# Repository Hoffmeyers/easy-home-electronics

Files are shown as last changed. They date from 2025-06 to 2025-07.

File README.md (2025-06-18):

This KiCad project showcases the design of a smart switch system built around the ESP32 microcontroller, aimed at enhancing automation and energy monitoring in residential or commercial settings. The system integrates both 5V and 3.3V low-dropout (LDO) voltage regulators to ensure stable power delivery to the ESP32 and associated components. An AC-DC converter is used to step down and convert mains voltage into usable DC power, making the switch compatible with standard household wiring. Additionally, the circuit incorporates voltage and current sensors to enable real-time power consumption monitoring, allowing users to track energy usage and implement protective features. The layout is optimized for compactness and reliability, with clear signal routing and robust power distribution.

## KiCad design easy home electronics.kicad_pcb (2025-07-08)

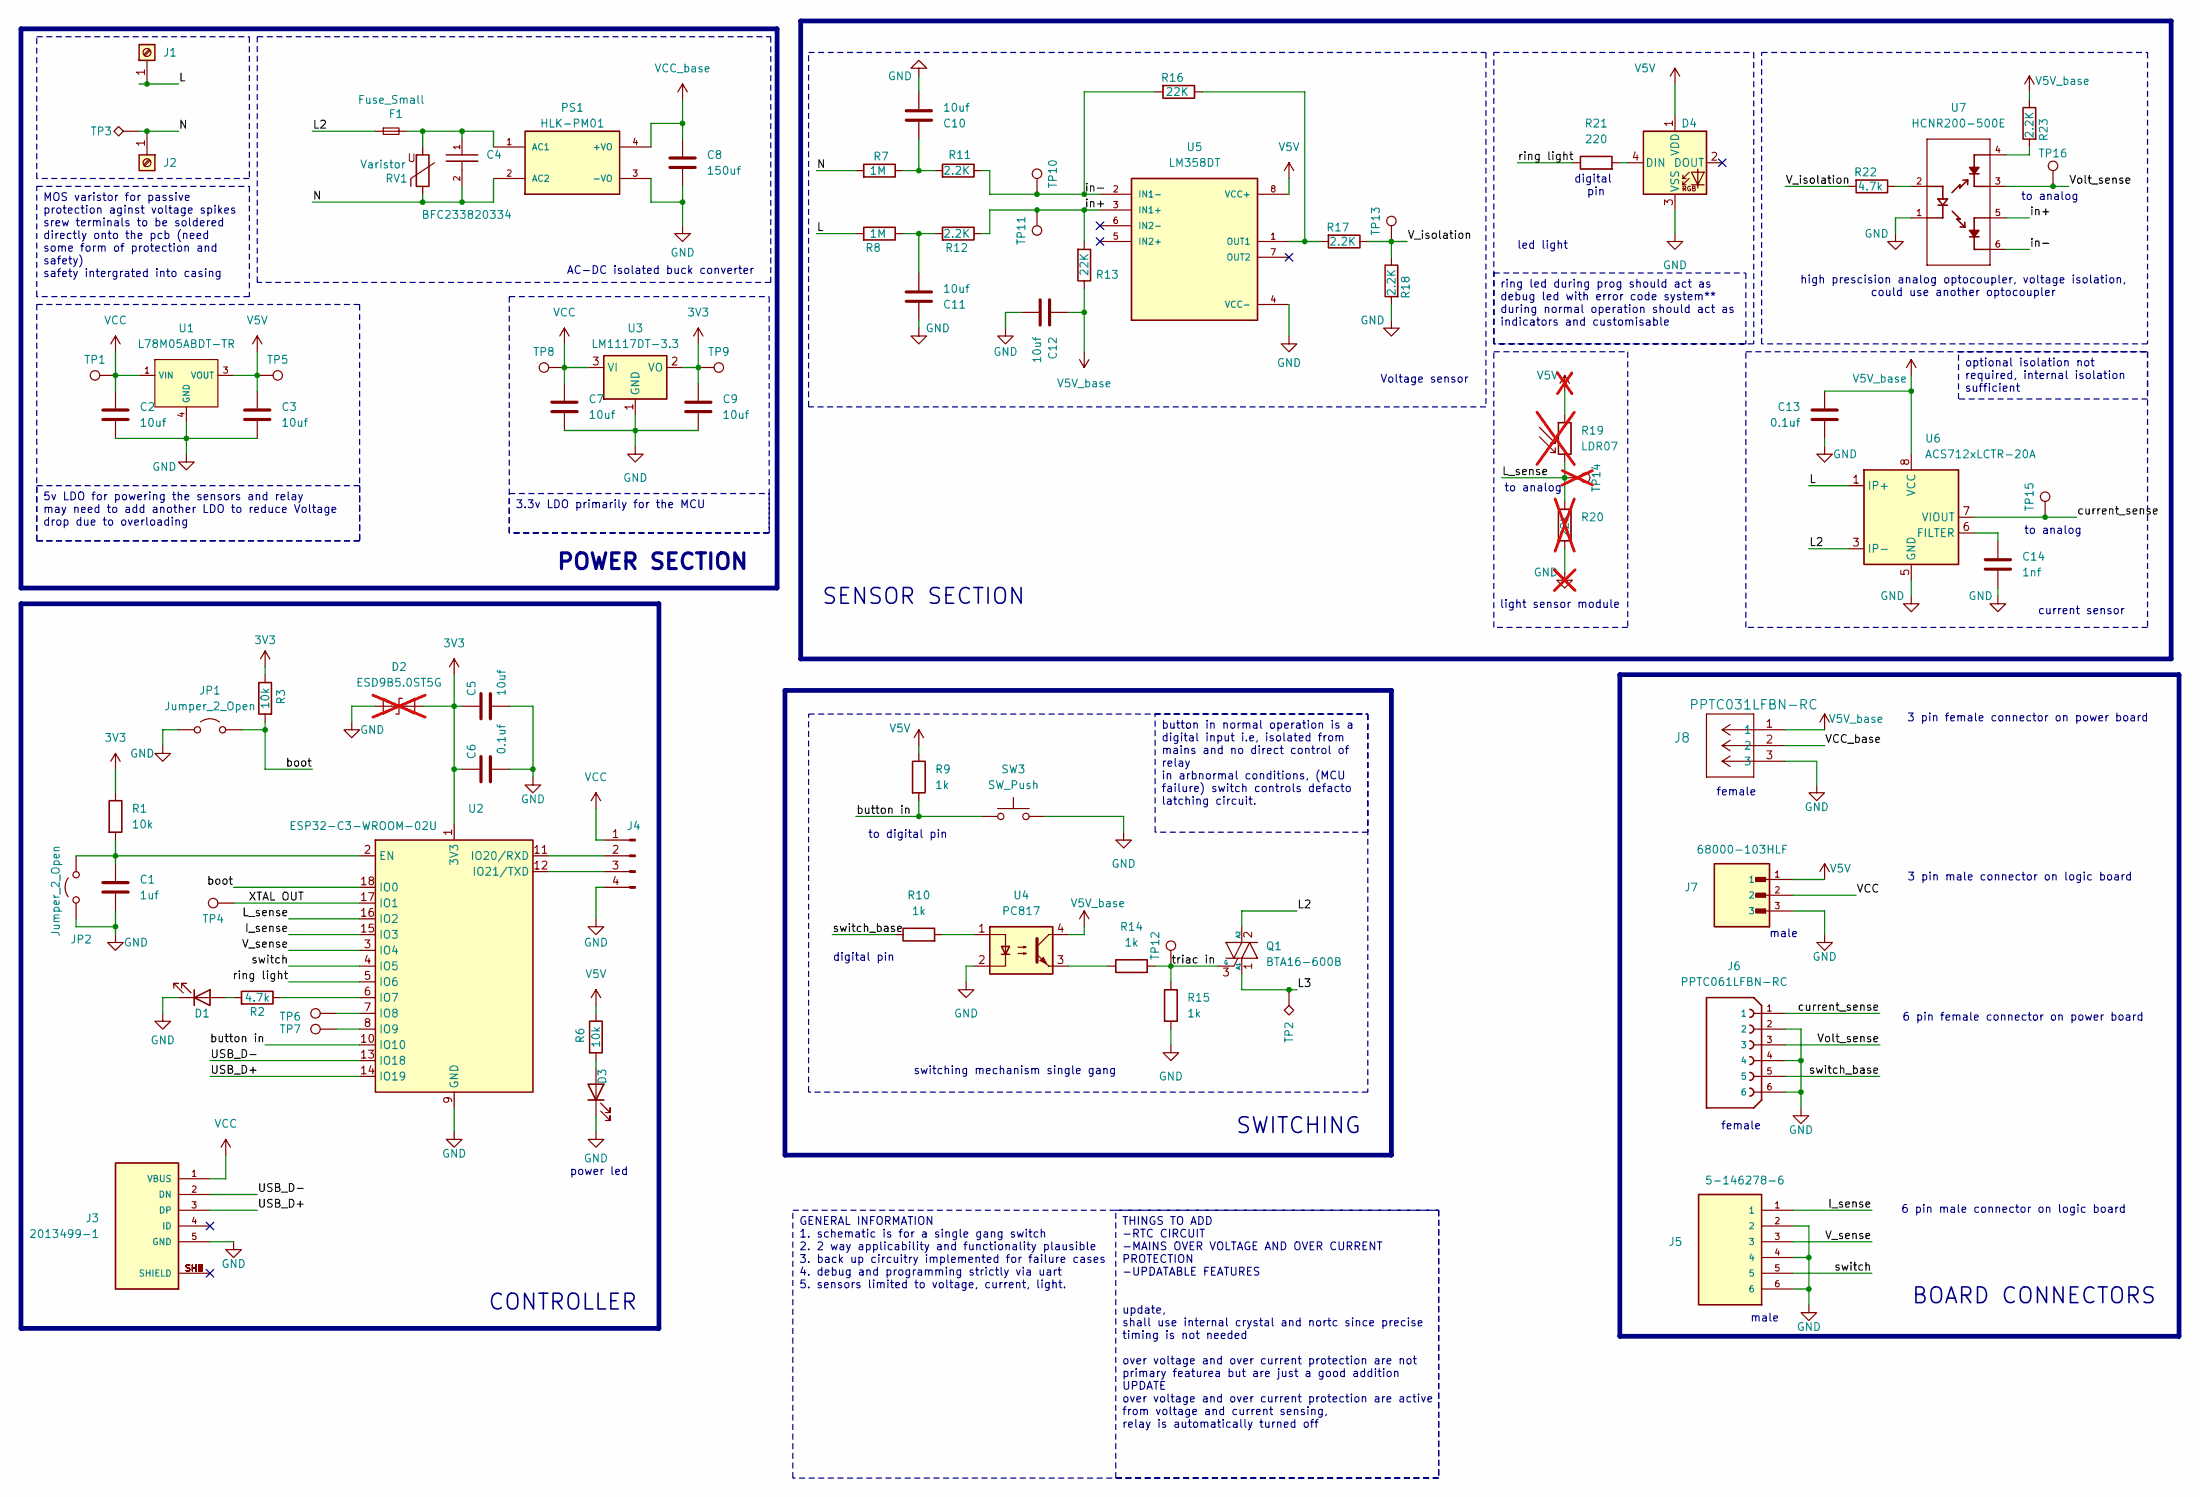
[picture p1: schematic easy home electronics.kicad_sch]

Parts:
C1: 1uf; C_1812_4532Metric
C2, C3, C5, C7, C9, C10, C11, C12: 10uf; C_1812_4532Metric
C4: BFC233820334; CAPRR1500W80L1750T850H1500P
C6, C13: 0.1uf; C_1812_4532Metric
C8: 150uf; C_Elec_6.3x7.7
C14: 1nf; C_1812_4532Metric
D1, D3: LED; LED_1206_3216Metric
D2: ESD9B5.0ST5G; D_SOD-923; not fitted
D4: WS2812B; LED_WS2812B_PLCC4_5.0x5.0mm_P3.2mm
F1: Fuse_Small; Fuse_2512_6332Metric
J1, J2: Screw_Terminal_01x01; MountingHole_3mm_Pad_Via
J3: 2013499-1; TE_2013499-1; PARTREV B5
J4: Conn_01x04_Pin; Molex_PicoBlade_53261-0471_1x04-1MP_P1.25mm_Horizontal
J5: 5-146278-6; TE_5-146278-6; PARTREV R
J6: PPTC061LFBN-RC; SULLINS_PPTC061LFBN-RC; PARTREV L
J7: 68000-103HLF; AMPHENOL_68000-103HLF; PARTREV DG
J8: PPTC031LFBN-RC; CONN_PPTC031_SUL
JP1, JP2: Jumper_2_Open; SolderJumper-2_P1.3mm_Open_TrianglePad1.0x1.5mm
PS1: HLK-PM01; CONV_HLK-PM01
Q1: BTA16-600B; TO-220-3_Vertical
R1, R3, R6: 10k; R_1812_4532Metric_Pad1.30x3.40mm_HandSolder
R2, R22: 4.7k; R_1812_4532Metric_Pad1.30x3.40mm_HandSolder
R7, R8: 1M; R_1812_4532Metric_Pad1.30x3.40mm_HandSolder
R9, R10, R14, R15: 1k; R_1812_4532Metric_Pad1.30x3.40mm_HandSolder
R11, R12, R17, R18, R23: 2.2K; R_1812_4532Metric_Pad1.30x3.40mm_HandSolder
R13, R16: 22K; R_1812_4532Metric_Pad1.30x3.40mm_HandSolder
R19: LDR07; R_LDR_5.1x4.3mm_P3.4mm_Vertical; not fitted
R20: 22K; R_1812_4532Metric_Pad1.30x3.40mm_HandSolder; not fitted
R21: 220; R_1812_4532Metric_Pad1.30x3.40mm_HandSolder
RV1: Varistor; RV_Disc_D12mm_W3.9mm_P7.5mm
SW3: SW_Push; SW_PUSH_6mm_H5mm
TP1, TP4, TP5, TP6, TP7, TP8, TP9, TP10, TP11, TP12, TP13, TP15, TP16: TestPoint; TestPoint_Pad_D2.5mm
TP2, TP3: TestPoint_Alt; TestPoint_Pad_4.0x4.0mm
TP14: TestPoint; TestPoint_Pad_D4.0mm; not fitted
U1: L78M05ABDT-TR; TO-252-2_L6.5-W6.1-P4.58-LS10.0-TL; Output Voltage 5V; Part L78M05ABDT-TR; LCSC C58069
U2: ESP32-C3-WROOM-02U
U3: LM1117DT-3.3; TO-252-3_TabPin2
U4: PC817; DIP-4_W7.62mm
U5: LM358DT; SOIC127P600X175-8N
U6: ACS712xLCTR-20A; SOIC-8_3.9x4.9mm_P1.27mm
U7: HCNR200-500E; OPTO_HCNR200-500E

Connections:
3V3: C5.1, C6.1, C9.1, D2.2 (A2), R1.1, R3.1, TP9.1, U2.1 (3V3), U3.2 (VO)
/I_sense: J5.1, U2.15 (IO3)
/L: J1.1, R8.2, U6.1 (IP+), U6.2 (IP+)
/L2: F1.1, Q1.2 (A2), U6.3 (IP-), U6.4 (IP-)
/L3: Q1.1 (A1), TP2.1
/L_sense: R19.2, R20.1, TP14.1, U2.16 (IO2)
/N: C4.2, J2.1, PS1.2 (AC2), R7.2, RV1.1, TP3.1
/USB_D+: J3.3 (DP), U2.14 (IO19)
/USB_D-: J3.2 (DN), U2.13 (IO18)
/V_isolation: R17.1, R18.1, R22.2, TP13.1
/V_sense: J5.3, U2.3 (IO4)
/Volt_sense: J6.3, TP16.1, U7.3
/XTAL OUT: TP4.1, U2.17 (IO1)
/boot: JP1.2 (B), R3.2, U2.18 (IO0); also elsewhere on the board
/button in: R9.2, SW3.1, U2.10 (IO10)
/current_sense: J6.1, TP15.1, U6.7 (VIOUT)
/in+: R12.1, R13.2, TP11.1, U5.3 (IN1+), U7.5
/in-: R11.1, R16.2, TP10.1, U5.2 (IN1-), U7.6
/ring light: R21.1, U2.5 (IO6)
/switch: J5.5, U2.4 (IO5)
/switch_base: J6.5, R10.1
/triac in: Q1.3 (G), R14.2, R15.1, TP12.1
GND: C1.2, C2.2, C3.2, C5.2, C6.2, C7.2, C8.2, C9.2, C10.2, C11.1, C12.2, C13.2, C14.2, D1.1 (K), D2.1 (A1), D3.1 (K), D4.3 (VSS), J3.5 (GND), J4.4, J5.2, J5.4, J5.6, J6.2, J6.4, J6.6, J7.3, J8.3, JP1.1 (A), JP2.1 (A), PS1.3 (-VO), R15.2, R18.2, R20.2, SW3.2, U1.4 (GND), U2.9 (GND), U2.19 (GND), U3.1 (GND), U4.2, U5.4 (VCC-), U6.5 (GND), U7.1; also elsewhere on the board
unnamed: C10.1, R7.1, R11.2
unnamed: C11.2, R8.1, R12.2
unnamed: D1.2 (A), R2.2
unnamed: D3.2 (A), R6.2
unnamed: D4.4 (DIN), R21.2
unnamed: J4.2, U2.11 (IO20/RXD)
unnamed: J4.3, U2.12 (IO21/TXD)
unnamed 30: C1.1, JP2.2 (B), R1.2, U2.2 (EN); also elsewhere on the board
unnamed: C4.1, F1.2, PS1.1 (AC1), RV1.2
unnamed: R10.2, U4.1
unnamed: R14.1, U4.3
unnamed: R22.1, U7.2
unnamed: R23.2, U7.4
unnamed: R2.1, U2.6 (IO7)
unnamed: TP6.1, U2.7 (IO8)
unnamed: TP7.1, U2.8 (IO9)
unnamed: R16.1, R17.2, U5.1 (OUT1)
unnamed: C14.1, U6.6 (FILTER)
V5V: C3.1, D4.1 (VDD), J7.1, R6.1, R9.1, R19.1, TP5.1, U1.3 (VOUT), U5.8 (VCC+)
V5V_base: C12.1, C13.1, J8.1, R13.1, R23.1, U4.4, U6.8 (VCC)
VCC: C2.1, C7.1, J3.1 (VBUS), J4.1, J7.2, TP1.1, TP8.1, U1.1 (VIN), U3.3 (VI)
VCC_base: C8.1, J8.2, PS1.4 (+VO)

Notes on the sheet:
power led
high prescision analog optocoupler, voltage isolation, could use another optocoupler
led light
current sensor
3 pin male connector on logic board
light sensor module
male
to analog
SENSOR SECTION
digital pin
3 pin female connector on power board
CONTROLLER
BOARD CONNECTORS
SWITCHING
switching mechanism single gang
Voltage sensor
digital pin
6 pin male connector on logic board
female
to digital pin
6 pin female connector on power board
AC-DC isolated buck converter
POWER SECTION
optional isolation not required, internal isolation sufficient
THINGS TO ADD -RTC CIRCUIT -MAINS OVER VOLTAGE AND OVER CURRENT PROTECTION -UPDATABLE FEATURES update, shall use internal crystal and nortc since precise timing is not needed over voltage and over current protection are not primary featurea but are just a good addition UPDATE over voltage and over 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
MOS varistor for passive protection aginst voltage spikes srew terminals to be soldered directly onto the pcb (need some form of protection and safety) safety intergrated into casing
GENERAL INFORMATION 1. schematic is for a single gang switch 2. 2 way applicability and functionality plausible 3. back up circuitry implemented for failure cases 4. debug and programming strictly via uart 5. sensors limited to voltage, current, light.
3.3v LDO primarily for the MCU
button in normal operation is a digital input i.e, isolated from mains and no direct control of relay in arbnormal conditions, (MCU failure) switch controls defacto latching circuit.
ring led during prog should act as debug led with error code system** during normal operation should act as indicators and customisable
5v LDO for powering the sensors and relay may need to add another LDO to reduce Voltage drop due to overloading

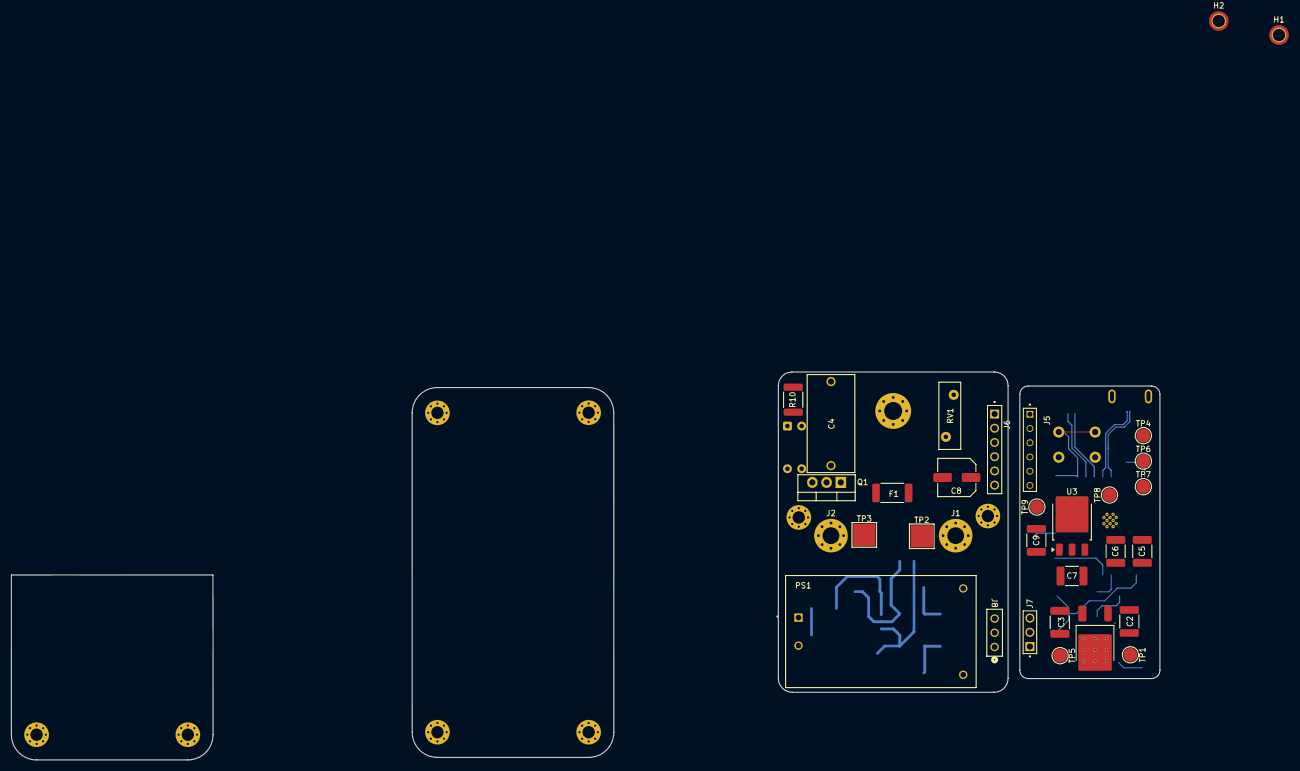
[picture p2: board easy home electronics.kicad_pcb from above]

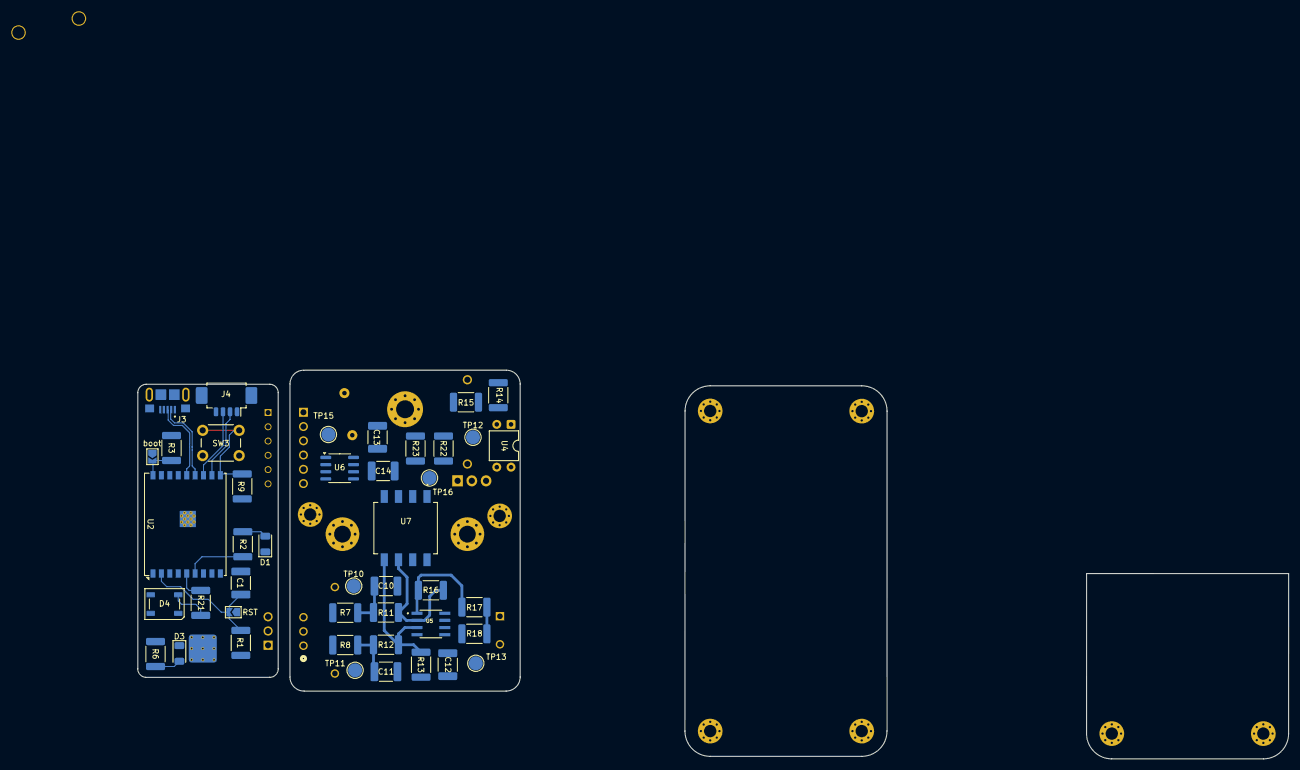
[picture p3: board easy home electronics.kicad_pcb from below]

Board: 4 copper layers, 205.0 x 69.2 mm, 75 parts (43 on the bottom side), 44 nets.

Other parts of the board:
H1, H2: MountingHole_Pad_MP; MountingHole_2.2mm_M2_ISO7380_Pad_TopOnly
RST: Jumper_2_Open; SolderJumper-2_P1.3mm_Open_TrianglePad1.0x1.5mm
boot: Jumper_2_Open; SolderJumper-2_P1.3mm_Open_TrianglePad1.0x1.5mm

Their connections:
/boot: boot.2 (B); also elsewhere on the board
GND: RST.1 (A), boot.1 (A); also elsewhere on the board
unnamed 30: RST.2 (B); also elsewhere on the board
